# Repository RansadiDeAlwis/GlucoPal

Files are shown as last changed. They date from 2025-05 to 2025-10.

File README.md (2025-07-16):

# GlucoPal 🩺 – Non-Invasive Blood Glucose Monitoring  
**Team NeuroBytes | University of Moratuwa**

---

## 🔍 Project Overview

**GlucoPal** is a **non-invasive, low-cost, portable device** for real-time blood glucose monitoring using **Near-Infrared (NIR) spectroscopy** and **Photoplethysmography (PPG)**. The system addresses the global diabetes epidemic, particularly in regions like **Sri Lanka**, where **20% of adults** are diabetic or pre-diabetic—many undiagnosed due to lack of screening tools.

**Goal:** Eliminate painful and costly finger-prick tests through a user-friendly device powered by optical sensing and AI.

---

## ⚙️ How It Works

1. **Finger Placement**: User places a finger on a 3D-printed sensor clip.
2. **Signal Acquisition**: A 940nm IR emitter/receiver captures PPG signals.
3. **Signal Processing**: ESP32 microcontroller amplifies, filters, and transmits data to a Raspberry Pi.
4. **Model Inference**: A trained **1D ResNet34 model** predicts glucose levels from the PPG data.
5. **Display Output**: Results are shown on an onboard OLED display.

---

## 🧪 Technologies Used

- **Hardware**: ESP32, IR emitter/receiver (940nm), TL084 op-amp, Raspberry Pi, OLED Display
- **Software**: PyTorch, SciPy, NumPy, Matplotlib
- **AI Model**: Customized **1D ResNet34** for regression
- **Signal Features**: Filtering, downsampling, normalization, segmentation
- **Cloud Integration**: **AWS Lambda**, **Amazon S3**, **Amazon DynamoDB**, **MQTT via AWS IoT Core**

---

## ☁️ Cloud Infrastructure (AWS Integration)

GlucoPal is designed with **IoT connectivity and cloud-based data management**, providing secure and scalable storage, processing, and analysis.

### AWS Components

| Service | Role |
|---|---|
| **AWS Lambda** | Serverless preprocessing, validation, and forwarding |
| **Amazon S3** | Stores raw and processed PPG signal data, logs, backups |

---

### Data Flow
ESP32 → AWS → ML Model → ESP32 → Display

---

### Why Cloud?

- **Remote Access**: Patients and clinicians can access historical glucose data remotely.
- **Scalability**: No limits on data storage or concurrent users.
- **Security**: AWS IoT Core ensures secure MQTT communication with TLS.
- **Cost-Effective**: Pay-per-use model via AWS Lambda & S3.
- **Alerts & Automation**: Easy to integrate with AWS SNS or other health record systems.

---

## 🧬 Dataset

- **Source**: University of Science and Technology of Mazandaran, Iran
- **Type**: PPG signals at 2175Hz, labeled with glucose levels

### Preprocessing Pipeline

- Downsampling to **100Hz**
- Bandpass filtering (**0.5–8 Hz**)
- Zero-phase filtering & normalization
- Segmentation into **1-second windows**

---

## 📊 Model Performance

| Metric | Value |
|---|---|
| **Architecture** | Custom **1D ResNet34** |
| **RMSE** | 16.42 mg/dL |
| **MAE** | 13.41 mg/dL |
| **Clarke Error Grid** | Zone A & B (clinically acceptable) |
| **Inference Device** | Raspberry Pi |

---

## 🛠️ Features

- **Non-invasive** measurement
- **On-device display** via OLED
- **Wireless real-time communication** (ESP32 ↔ Raspberry Pi ↔ AWS)
- **Cloud-based storage and alerts**
- **Reusable, sustainable design** (no strips needed)
- **Low-cost components**, locally sourced

---

## Testing Frame

---

## 🔐 Ethics & IP

- **Ethical clearance** in progress for clinical testing.
- **No Personally Identifiable Information (PII)** is stored.
- **Intellectual Property** includes:
  - Custom signal acquisition circuitry
  - 3D-printed ergonomic enclosure
  - Cloud-integrated AI processing pipeline

---

## 🚀 Future Improvements

- **On-device AI inference** (eliminate Raspberry Pi dependency)
- **Edge processing with AWS Greengrass**
- **Clinical fine-tuning** with Sri Lankan patient data
- **Fully portable version** with LTE/Mobile MQTT connectivity

---

## 👨‍🔬 Team NeuroBytes

- **W. M. Ransadi de Alwis**  
- **Pravindu Goonetilleke**  
- **Mohamed Irshad Nadha**  
- **Pulasthi H. J. Udugamasooriya**

### Mentors

- Dr. Navoda Atapattu (Lady Ridgeway Hospital)  
- Dr. Nayana S. Fernando (UoM Faculty of Medicine)

---

## 📘 References

- [PPG Glucose Estimation Research](https://pmc.ncbi.nlm.nih.gov/articles/PMC10331674/)
- [PPG Dataset – Mendeley Data](https://doi.org/10.17632/37pm7jk7jn.3)

---

**Empowering early diabetes detection with innovation and accessibility.**

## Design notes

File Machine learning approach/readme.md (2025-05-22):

# 🤖 GlucoPal: Machine Learning for Non-Invasive Glucose Prediction

This repository contains the machine learning pipeline for **GlucoPal**, a non-invasive glucometer using PPG signals and deep learning. This component is responsible for predicting blood glucose levels from optical signals acquired through an ESP32-based sensor.

---

## 📁 Dataset

- **Source**: [University of Science and Technology of Mazandaran (MUST), Iran](https://doi.org/10.17632/37pm7jk7jn.3)
- **Samples**: 67 raw PPG signals from 23 individuals
- **Sampling Rate**: 2175 Hz
- **Features**:
  - Green LED (550 nm) PPG signals
  - Age, gender
  - Invasively measured blood glucose levels
download (3)

---

## 🛠️ Preprocessing Steps

1. **Downsampling**:
   - From 2175 Hz → 100 Hz using linear interpolation
2. **Filtering**:
   - 3rd-order Butterworth bandpass (0.5–8 Hz) via `scipy.signal`
   - Zero-phase filtering to preserve temporal structure
3. **Normalization**:
   - Standardization to zero mean and unit variance
4. **Segmentation**:
   - Split into 1-second windows (100 samples per segment)

---

## 🧠 Model Architecture – 1D ResNet34

A custom 1D version of ResNet34 was implemented using **PyTorch** for time-series PPG regression.

### 🔧 Structure Overview

- **Input**: (batch_size, 1, 100)
- **Initial Conv1D Layer** (64 filters, kernel size 7) + BatchNorm + ReLU + MaxPooling
- **Residual Blocks**:
  - 3 × [64 filters]
  - Transition: Conv1D → 128
  - 3 × [128 filters]
  - Transition: Conv1D → 256
  - 3 × [256 filters]
- **Global Average Pooling**
- **Dense Layer** (256 units + ReLU)
- **Dropout** (0.5)
- **Output**: 1 neuron (regression output)

---

## 🏋️‍♂️ Training Details

- **Framework**: PyTorch
- **Loss Function**: Mean Squared Error (MSE)
- **Optimizer**: Adam
- **Batch Size**: 64
- **Epochs**: 50 (adjustable)
- **Validation Split**: 20%

---

## 📊 Model Performance

### 📈 Evaluation Metrics
- **Root Mean Squared Error (RMSE)**: `16.42 mg/dL`
- **Mean Absolute Error (MAE)**: `13.41 mg/dL`
- **Clarke Error Grid Analysis**:
  - Majority of predictions in Zones **A** & **B** (clinically acceptable)
  - Minimal predictions in Zones C–E
 
download (1)

## Testing the model 
download (2)

---

## 🖥️ Inference Pipeline

- The trained model runs on a **Raspberry Pi**, receiving PPG data from an ESP32 over Wi-Fi.
- Preprocessing and inference are done on-device using the trained PyTorch model.
- Output is transmitted back to the ESP32 and displayed on an OLED screen.

---

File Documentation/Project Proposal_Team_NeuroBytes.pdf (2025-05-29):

# Non-Invasive Glucometer Using NIR and Photoplethysmography

## Team NeuroBytes

### University of Moratuwa

### GlucoPal

## Team NeuroBytes

Team Leader

W. M. Ransadi de Alwis

200280501137

dealwiswmr.22@uom.lk

0742239385

2nd Year

Team Member 1

Pravindu Goonetilleke

200230802158

goonetillekep.22@uom.lk

0772111411

2nd Year

Team Member 2

Mohamed Irshad Nadha

200253202440

nadhami.22@uom.lk

0771685092

2nd Year

Team Member 3

Pulasthi H. J.
Udugamasooriya

200206100439

udugamasooriyaphj.22@u
om.lk

0716167955

2nd Year

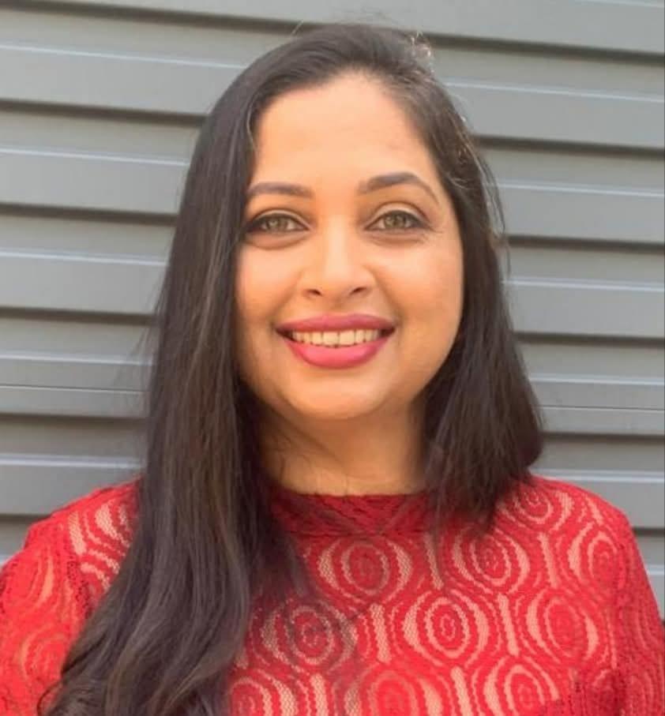
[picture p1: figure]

Team Mentor 1 | Team Mentor 2
Dr. Navoda Atapattu | Dr. Nayana Shiranthini Fernando
738622790V | 715232529V
navodaa@gmail.com | nayanaf@uom.lk
0772995039 | 0777931062
Pediatric Endocrinologist | MBBS,MSc,MD (Community Medicine)
Lady Ridgeway Hospital | Senior Lecturer
| Faculty of Medicine
| University of Moratuwa

## Near-Infrared-Based Glucometer Proposal

## 1. Problem being Addressed and Why it is Important

Diabetes, one of the most common chronic diseases that people have throughout their lives, is expected to surpass all other causes of death in the near future. Diabetes is an autoimmune disease brought on by the body's incapacity to control glucose, or sugar, in the body. While diabetes in itself is harmful, improper treatment of diabetes worsens the situation, by harming and causing other delicate organs in the body to malfunction.

According to the International Diabetes Federation (IDF), 540 million adults, or 10.5% of the global population, had diabetes in 2021. Without effective prevention strategies, this number is projected to rise to 783 million (12.2%) by 2045. In the same year, diabetes was responsible for 6.7 million deaths and incurred healthcare costs amounting to $966 billion, marking a staggering 316% increase over the past 15 years. Additionally, an estimated 541 million individuals worldwide had pre-diabetes in 2021, placing them at a high risk of developing type 2 diabetes. The burden of diabetes disproportionately affects low- and middle-income countries, where three out of four individuals with the condition reside, with many remaining undiagnosed.

Sri Lanka, a country with a population of 22 million, is experiencing a steady rise in diabetes and pre-diabetes cases. Currently, 20% of Sri Lankan adults aged 20 to 79 have either diabetes or pre-diabetes, and one-third of those with diabetes remain undiagnosed. Several factors contribute to this rising trend, including an aging population, increasing obesity rates, urbanization, and reduced physical activity. Between 2011 and 2021, the prevalence of type 2 diabetes surged from 7.6% to 11.3%, reflecting a 68.3% increase. [5] (https://pmc.ncbi.nlm.nih.gov/articles/PMC10462943/)

Early detection and ongoing monitoring are essential to preventing complications and lowering healthcare costs, because of the high prevalence of diabetes and its life-altering effects. However, the lack of easily available and reasonably priced screening techniques means that a lot of people go untreated. By creating a novel, non-invasive diabetes detection and monitoring device, our project seeks to close this gap and offer a practical, affordable, and user-friendly way to enhance early diabetes diagnosis and management.

## 2. Process of Collecting Information about the Problem

We began our research on prevailing issues in the health sector by consulting several medical professionals. Our focus shifted to a specific issue suggested by a pediatric endocrinologist (now acting as our mentor) based on the widespread relevance and influence it has on the healthcare sector; the issue of inconvenience and discomfort presented to diabetic patients, especially children, by the common invasive procedure of measuring blood sugar involving pricking a finger. She emphasized that the issue has been an unaddressed inconvenience in Sri Lanka for a significant time, not only to patients but also to medical professionals like herself.

With an initial idea based on her insights, we expanded our knowledge further by consulting research papers and studies about the issue to better understand the problem. We were able to find a number of studies that recognized this issue [2] [3] [4] [6], and called for the urgent need of an economically feasible and reliable noninvasive procedure/product to measure blood glucose levels. Our research also included an investigation of such possible non-invasive procedures, after which we recognized NIR technology and PPG waveforms as two of the most promising procedures, and decided to develop GlucoPal based on them.

## 3. Brief Description of the Solution

### Overview

Diabetes management relies on accurate blood glucose monitoring, which is traditionally done through invasive blood sampling via pricks. Pricking is often painful, requires expensive test strips, and is not a viable option for continuous glucose monitoring.

This project aims to develop a non-invasive near-infrared (NIR)-based glucometer utilizing an IR emitter and receiver (940nm) to measure blood glucose levels from the finger. The proposed solution will process photoplethysmographic (PPG) signals and peak IR values to train machine learning models for accurate glucose prediction.

### Methodology

1. Hardware Setup
- Use an IR emitter (940nm) and receiver to measure light absorption variations through a fingertip.
- Process the analog signals from the sensor using a microcontroller.
- Convert the analog values into a continuous PPG waveform and extract peak values separately.
2. Signal Processing & Data Collection
- The IR receiver will capture light absorption variations corresponding to blood volume changes.
- The continuous signal will be processed to generate a PPG waveform.
- Peak IR values will be extracted separately for a secondary data analysis approach.
- Data will be collected in correlation with actual blood glucose measurements.
3. Model Training
- PPG Waveform Model: Trained using the PPG waveform and corresponding blood glucose levels.
- Peak IR Value Model: Trained using peak IR values and corresponding blood glucose levels.
- Both models will be evaluated and validated using real-world data to enhance prediction accuracy.

### Rationale

The glucose molecule exhibits its highest absorption peak at 940nm [3], making near-infrared (NIR) sensing at this wavelength suitable for estimating blood glucose levels [7]. However, NIR-based methods alone have demonstrated limited correlation with actual blood glucose levels [3].

To enhance accuracy, we plan to capture Photoplethysmogram (PPG) signals, which measure volumetric blood flow changes using the same sensors. Integration of PPG signals into machine learning algorithms has shown improved predictive capability for blood glucose levels compared to infrared methods alone [3] [6] [8].

By leveraging both techniques, our goal is to significantly improve the accuracy of our device.

### Functional Diagrams

System Architecture

Data Flow

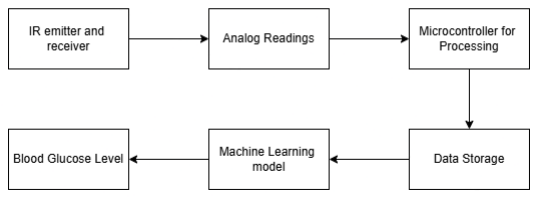
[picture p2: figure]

### Required Resources

Hardware

- 940nm IR emitter and receiver
- Microcontroller (e.g., Arduino, ESP32, or Raspberry Pi)
- Analog-to-Digital Converter (if required)
- Low Noise Amplifier
- Finger clip for sensor placement
- Power supply and necessary wiring

Software

- Python (for data processing and ML model training)
- Machine Learning frameworks (TensorFlow/PyTorch/Scikit-learn)
- Signal processing libraries (SciPy, NumPy, OpenCV for waveform extraction)

Data

- Collection of paired datasets (PPG waveform and blood glucose levels, Peak IR values and blood glucose levels)
- Datasets available online
- Clinical datasets / Volunteer data (if possible)
- Data pre-processing for noise reduction and feature extraction

### Novelty and Uniqueness

- Non-Invasive Glucose Monitoring: Unlike traditional glucometers, this system eliminates the need for finger pricking.
- Dual Model Approach: By using both PPG waveform and peak IR values, the system enhances accuracy and redundancy in glucose prediction.
- Machine Learning Integration: Advanced AI models will improve accuracy over time through adaptive learning.
- Real-Time Monitoring Potential: The system can be extended for continuous glucose monitoring, benefiting diabetic patients with real-time data insights.

### Market Analysis & Competitor Landscape

During our discussions with doctors, a critical pain point became evident: the traditional pricking method for glucose monitoring is far from ideal. It presents several challenges:

- Pain & Discomfort: Patients dislike the frequent finger pricks.
- High Cost: Test strips are expensive, making long-term use burdensome.
- Limited Feasibility for Continuous Monitoring: The method is impractical for real-time glucose tracking.

Recognizing these challenges, we conducted in-depth research and identified a significant market opportunity. While non-invasive glucose monitoring solutions are available globally, they are not widely used in Sri Lanka. Doctors confirmed that the high cost of existing solutions makes them inaccessible to most of Sri Lanka’s population.

This gap provides a unique first-mover advantage for us. By offering an affordable and accessible alternative, we can redefine glucose monitoring in Sri Lanka’s healthcare sector, making it feasible for both hospitals and individual patients.

### Existing Products

Right now, there aren’t many non-invasive glucometers on the market. This is mainly because it’s hard to make accurate predictions. Some devices do exist, but they have major drawbacks. For example, sugarBEAT [1] measures glucose using interstitial fluid (ISF), but ISF sugar levels lag behind the actual blood glucose levels by 4-10 minutes [2].

Other non-invasive glucometers also struggle with accuracy, ease of use, and consistency. Many of them use complex methods that don’t give results as reliable as traditional finger-prick tests.

Another big issue is cost. Most of these devices are very expensive, making them impractical for markets like Sri Lanka. Because of this, there’s still a big need for an affordable and accurate non-invasive glucometer in the country.

## 4. Impact of the Solution on Healthcare

### Impact on the Healthcare Sector

The introduction of a non-invasive glucometer based on Near-Infrared (NIR) sensing and Photoplethysmography (PPG) has the potential to revolutionize diabetes management in Sri Lanka and beyond. The healthcare sector, particularly in developing countries, faces multiple challenges in glucose monitoring, including high costs, limited accessibility, and patient discomfort with invasive methods. GlucoPal directly addresses these issues and provides significant benefits to multiple stakeholders, including patients, healthcare providers, and the government.

### Sustainability of GlucoPal

GlucoPal enhances sustainability by eliminating the dependence on disposable test strips, which contribute significantly to medical waste. Traditional glucose monitoring requires frequent pricking, leading to biohazardous waste and ongoing expenses. Our device, by utilizing Near-Infrared (NIR) technology and Photoplethysmography (PPG), removes the need for invasive procedures, reducing both environmental impact and healthcare costs. Additionally, the device is designed for long-term use with rechargeable batteries and durable components, ensuring minimal replacement needs. This approach not only minimizes medical waste but also provides a reliable, low-maintenance alternative for continuous glucose monitoring, making it a more sustainable choice for diabetes management.

### How GlucoPal Addresses the Problem Statement

Diabetes management relies heavily on frequent blood glucose monitoring, which is traditionally invasive, painful, and costly. GlucoPal directly addresses these challenges by leveraging Near-Infrared (NIR) technology and Photoplethysmography (PPG) to measure blood glucose levels non-invasively. This removes the need for frequent finger pricking, making it more comfortable for users while eliminating the recurring cost of test strips. Additionally, machine learning integration enhances accuracy over time, ensuring reliable glucose level estimation. By providing a practical alternative to conventional methods, our device enables better diabetes management without the drawbacks of invasive testing.

### How Customers Will Benefit from GlucoPal

- Pain-Free Monitoring: Eliminates the need for finger pricks, providing a more comfortable experience for diabetic patients.
- Cost-Effective: Reduces the financial burden by eliminating the need for costly test strips, making glucose monitoring more affordable.

- Increased Accessibility: Offers a practical solution for diabetes patients in Sri Lanka who struggle with the high cost of traditional glucometers.
- Continuous Monitoring: Enables real-time glucose tracking without discomfort, leading to better disease management and early intervention.
- Improved Healthcare Efficiency: Reduces the financial strain on healthcare institutions by offering a non-invasive alternative to traditional glucose testing.
- Better Long-Term Health Outcomes: Encourages frequent monitoring, helping patients manage their condition more effectively and reduce complications.

## 5. References

[1] https://www.medicalexpo.com/prod/nemaura-medical/product-112238-739565.html
[2] https://pmc.ncbi.nlm.nih.gov/articles/PMC7731259/
[3] https://sci-hub.se/downloads/2020-06-05/9a/priyoti2019.pdf
[4] https://pmc.ncbi.nlm.nih.gov/articles/PMC10331674/
[5] https://pmc.ncbi.nlm.nih.gov/articles/PMC10462943/
[6] https://www.mdpi.com/1424-8220/22/12/4452’
[7] https://sci-hub.se/https://doi.org/10.1109/ICAC49085.2019.9103375
[8] https://www.mdpi.com/2076-3417/14/4/1406

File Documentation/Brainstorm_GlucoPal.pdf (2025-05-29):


## University of Moratuwa

## Department of Electronic and Telecommunication Engineering

# Non-Invasive Glucometer Using NIR and Photoplethysmography

## (GlucoPal)

## Project Report

Team NeuroBytes

W. M. Ransadi de Alwis | 200280501137
Pravindu Goonetilleke | 200230802158
Mohamed Irshad Nadha | 200253202440
Pulasthi H. J. Udugamasooriya 200206100439

Mentors:

Dr. Navoda Atapattu – Pediatric Endocrinologist, Lady Ridgeway Hospital Dr. Nayana Shiranthini Fernando – Senior Lecturer, Faculty of Medicine, UoM

May 4, 2025

# Contents

1 Introduction | 3
2 Literature Review | 4
3 Feasibility | 7
4 Functionality | 9
5 Circuitry | 10
6 Enclosure Design | 16
7 Model Training and Results | 18
8 Simulation Results | 23

1

GlucoPal | Team NeuroBytes
9 Regulatory Aspects | 25
10 Data Security and Privacy | 27
11 Impact and Sustainability | 28
12 Limitations and Future Improvements | 29

2

# Chapter 1

# Introduction

## 1.1 Project Overview

Diabetes is a major global health issue and is rapidly becoming one of the leading causes of death. It occurs when the body fails to regulate blood glucose levels, leading to long-term complications that damage vital organs. As of 2021, over 540 million people worldwide were living with diabetes, with numbers projected to reach 783 million by 2045. Alarmingly, most of those affected live in low- and middle-income countries, where diagnosis and treatment are often delayed or inaccessible due to cost. In Sri Lanka, 20% of adults already have diabetes or pre-diabetes, with a third of cases going undiagnosed—largely due to limited screening options and growing lifestyle-related risk factors.

Traditional glucose monitoring methods are invasive and costly, making them impractical for widespread use in resource-limited settings like Sri Lanka. Continuous blood tests can be uncomfortable and unaffordable for many, especially for early detection or frequent monitoring. Our project addresses this gap by developing a non-invasive, low-cost, and user-friendly solution for diabetes detection and monitoring, aiming to improve accessibility, early diagnosis, and long-term health outcomes in communities most at risk.

3

# Chapter 2

# Literature Review

## 2.1 Optical Methods for Non-Invasive Glucose Monitoring

Among the various non-invasive techniques being explored, optical methods have shown promise [1]–[3]. These methods generally rely on the quantification of glucose molecules, which exhibit distinct characteristics when interacting with light at different frequencies, such as visible light, near-infrared (NIR), and ultrasonic waves [1]. While optical methods enable real-time quantitative monitoring, they have faced challenges in matching the accuracy of traditional electrochemical blood glucose meters in clinical settings [1].

### 2.1.1 Near-Infrared (NIR) Spectroscopy

Near-infrared spectroscopy is a promising non-invasive blood glucose monitoring technology [1], [2]. The principle involves analyzing a beam of infrared light that passes through or is reflected by human tissue to determine glucose content [1]. Glucose molecules interact with NIR light, causing absorption and scattering [1]. NIR light is particularly effective as it can penetrate body fluids and soft tissues [1]. The concentration of blood sugar can be estimated by detecting and calibrating the NIR spectrum absorption value after the light has partially absorbed while passing through human tissue [1].

Glucose molecules exhibit distinct absorption patterns in the 700–1100 nm wavelength region, which is also where most biological cells and tissues are relatively transparent [2]. Wavelengths around 780 nm and 940 nm are noted for their reaction in response to glucose concentration [2]. Specifically, 940 nm is considered a reliable wavelength for glucose detection because it has a relatively high absorption value for glucose in blood compared to other blood components and exhibits less interference from water absorption than wavelengths above 1000 nm [2]. The relationship between substance concentration and light absorption/transmittance is described by Beer-Lambert’s law, where the decrease in light intensity is proportional to the concentration and path length [2]. By detecting the amount of transmitted light, the concentration can be calculated [2].

## 2.2 Photoplethysmography (PPG)

Photoplethysmography (PPG) is a non-invasive optical technique used to detect blood volume changes in the peripheral circulatory system [3], [4]. PPG signals can be obtained

4

from various body sites, such as the wrist, fingertip, or earlobe [3], [4]. The signal is generated by shining light (e.g., from LEDs at different wavelengths) into the tissue and measuring the light that is transmitted or reflected using a photodetector [4]. The amount of light absorbed or scattered varies with the pulsatile blood flow and the composition of the tissue and blood, including glucose levels [1], [2]. Glucose affects light scattering; a rise in glucose levels leads to decreased scattering and reduced total absorbed light [1].

Recent advancements in PPG technology, coupled with machine learning, have shown promise for non-invasive and economical blood glucose monitoring [4]. Studies have focused on using PPG signals from various sites, including the wrist, to estimate blood glucose levels [4].

## 2.3 Studies Combining NIR and PPG

Several research efforts have explored combining NIR principles with PPG for non-invasive glucose estimation. One study proposed a non-invasive blood glucose measurement system using Near Infra-Red Spectroscopy at a 940 nm wavelength [2]. This system utilizes a 940 nm IR emitter and a photodiode receiver, typically placed on a fingertip, to measure the amount of NIR radiation passing through the blood vessels [2]. The voltage output of the photodiode, which depends on the transmitted light, is correlated with blood glucose concentration [2].

A key challenge in such optical measurements is the influence of tissue thickness or width, as absorbance is directly proportional to the path length of light [2]. To compensate for variations in finger depth, one proposed method involves using an additional IR sensor to optically measure the distance between the emitter and receiver and normalize the IR absorbance readings to eliminate the effect of finger width [2].

Another approach combines dual-wavelength PPG (using 660 nm red light and 900 nm infrared light) with bioelectrical impedance measurements to estimate blood glucose [3]. The study noted that glucose has different absorption rates for different wavelengths [3].

## 2.4 Feature Extraction and Data Analysis

Extracting meaningful features from the acquired optical signals is crucial for accurate glucose estimation. For PPG signals, this can involve analyzing the waveform’s characteristics. Statistical features such as the mean, variance, skewness, kurtosis, standard deviation, and information entropy derived from PPG signal peaks have been used [3].

Once features are extracted, machine learning algorithms are applied to build predictive models for blood glucose levels [3], [4]. Techniques explored include polynomial regression [2], Back-Propagation Neural Networks (BPNN) [3], and various gradient boosting algorithms such as CatBoost, XGBoost, LightGBM, and random forest [4]. Studies have shown that these machine learning algorithms can achieve high levels of accuracy in predicting blood glucose from PPG and other physiological signals, with performance evaluated using metrics like Pearson’s r, Mean Squared Error (MSE), Mean Absolute Error (MAE), R2 score, and Clarke Error Grid Analysis (EGA) [3], [4]. Combining different types of features, such

5

as PPG waveform-based features and EMD-based features, can improve overall prediction accuracy [4]. The combination of dual-wavelength PPG and bioelectrical impedance features using a BPNN achieved an R2 of 0.997 and 100% of results in the clinically accurate region A of the Clarke EGA in one study [3].

## 2.5 Challenges

Despite significant progress, several technical bottlenecks hinder the widespread application and accuracy of non-invasive blood glucose monitoring technologies, including those based on optical methods like NIR spectroscopy and PPG [1], [3], [4]. Key challenges include:

- Weak signal detection: The signal related to glucose can be weak and requires effective amplification methods [1].
- Individual variations: Measurement accuracy is impacted by individual differences in human physiology and dynamic changes in body components [1].
- Measurement site: Identifying effective and consistent measurement sites (such as fingers or tongue tips) and developing supporting facilities for dynamic monitoring is necessary [1].
- Spectral overlap: Overlapping spectra from various tissue components make it challenging to accurately extract glucose-specific information, requiring effective extraction methods [1].
- Signal Noise and Artifacts: Motion artifacts and other noise can affect signal quality and accuracy, requiring signal processing techniques like filtering [3].
- Accuracy vs. Invasive Methods: The accuracy of current non-invasive technologies is still often not comparable to mainstream invasive methods in clinical practice [1].

6

# Chapter 3

# Feasibility

## 3.1 Hardware Components

Component | Available At (Store + Link) | Price (LKR)
940nm IR Emitter | Tronic LK (https://tronic.lk/product/ir-led-5mm-infrared-emitter-940nm) | 10
940nm IR Receiver | Tronic LK (https://tronic.lk/product/ir-led-5mm-infrared-receiver-940nm) | 20
ESP32 Microcontroller | Tronic LK (https://tronic.lk/product/nodemcu-esp32s-wifi-bluetooth-dual-mode-iot-dev-board) | 1340
Raspberry Pi | Tronic LK (https://tronic.lk/product/raspberry-pi-4-model-b-2gb-original-uk) | 23600**
TL084CN Operational Amplifier | Tronic LK (https://tronic.lk/product/tl084cn-amplifier) | 50
3D Printed Finger Clip | Rysera (https://3dprinting.rysera.com/) | 4000*
Li-Po Battery (1200mAh, 3.7V) | Tronic LK (https://tronic.lk/product/3-7v-1200mah-lipo-battery) | 900
Boost Converter (XL6009) | Tronic LK (https://tronic.lk/product/xl6009-3-32v-to-5-35v-4a-dc-to-dc-adjustable-step-up-bo) | 300
Charging Module (TP4056) | Tronic LK (https://tronic.lk/product/tp4056-5v-1a-micro-usb-18650-special-lithium-battery-ch) | 60
OLED Display (SSD1306 128x64) | Tronic LK (https://tronic.lk/product/0-96-inch-128x64-oled-display-module-blue-i2c-iic) | 540
Custom PCB (if needed) | JLCPCB (International Shipping) (https://jlcpcb.com) | 6000*
Total Cost | | 36,820

Table 3.1: Component List with Source and Estimated Price

*Prices for the PCB and 3D printing are approximate, and can be brought down when producing in bulk. Further, the PCB cost is for 5 PCBs (minimum order from JLCPCB.)

**Since the raspberry pi serves as a central server, it isn’t included in the price of GlucoPal.

## 3.2 Software and AI Technologies

- The deep learning model is developed using Pytorch.
- It will run on Raspberry Pi, a capable edge-computing device.
- The ESP32 captures PPG signals and transmits them to the Raspberry Pi via Wi-Fi.

7

- The Raspberry Pi runs inference using the trained model and sends the glucose value back to the ESP32.
- The OLED Display (SSD1306) shows the result to the user.

All hardware components are either available locally in Sri Lanka or can be fabricated using local services. Additionally, if needed, the custom PCB for the sensor circuit can be ordered from international PCB manufacturing services such as JLCPCB, (https://jlcpcb.com) which offers affordable pricing and fast shipping to Sri Lanka.

The selected technologies are feasible and practical for implementing a non-invasive glucometer using current embedded hardware and machine learning platforms.

8

# Chapter 4

# Functionality

The following outlines the end-to-end functionality of the non-invasive glucometer system:

1. Finger Placement: The user places their finger between a custom 3D-printed clip that houses the IR emitter and receiver.
2. PPG Signal Acquisition: A 940nm infrared emitter and receiver detect variations in light absorption caused by blood flow, producing a photoplethysmography (PPG) waveform.
3. Signal Conditioning: The weak analog PPG signal is amplified and filtered using a TL084CN operational amplifier configured as an instrumentation amplifier. This enhances signal clarity by reducing noise.
4. Microcontroller Sampling: The conditioned analog signal is read by the ESP32 microcontroller through its analog-to-digital converter (ADC). The ESP32 then sends this data wirelessly to a Raspberry Pi over Wi-Fi.
5. Signal Processing and Inference: The Raspberry Pi preprocesses the received signal by filtering and segmenting it. Each segment is passed through a trained machine learning model developed using TensorFlow. The model estimates the blood glucose level for each segment, removes outliers, and computes an average value.
6. Display Output: The final glucose level is sent back to the ESP32, which displays it on an OLED screen (SSD1306, 128x64 resolution).

9

# Chapter 5

# Circuitry

## Power Supply and Distribution

- A rechargeable 1200mAh Li-Po battery (2.7V nominal) serves as the primary power source.
- The battery is connected to both:

– A TP4056 charging module, which enables safe USB-based charging.

– An XL6009 boost converter, which steps up the voltage to 5V to power the main circuit.

- The 5V output from the boost converter is supplied to the PCB, which powers both the ESP32 microcontroller and the instrumentation amplifier circuit.

10

## Main PCB Layout

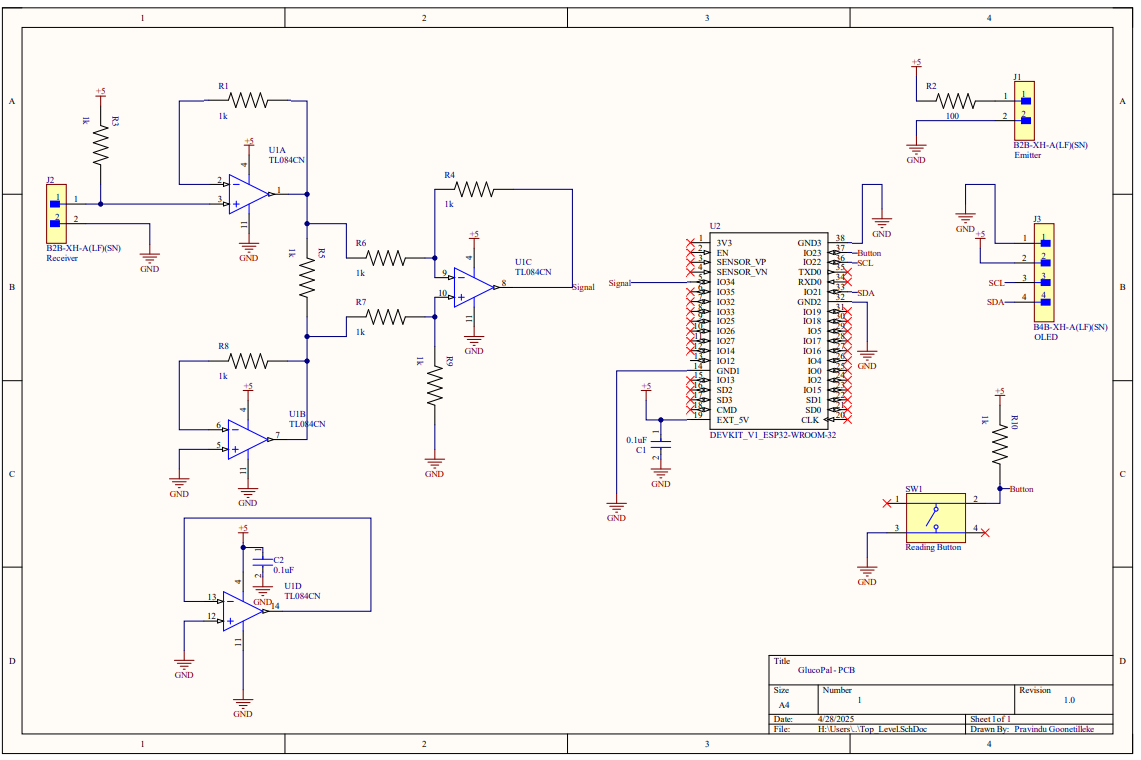
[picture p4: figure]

Figure 5.1: PCB schematic

- Sensor Inputs: JST connectors interface with the IR emitter and photodiode mounted in the finger clip.
- Instrumentation Amplifier: The PPG signal from the IR receiver is fed into a TL084CN-based instrumentation amplifier for amplification and noise suppression. The amplified signal is routed to the ADC pin of the ESP32.

11

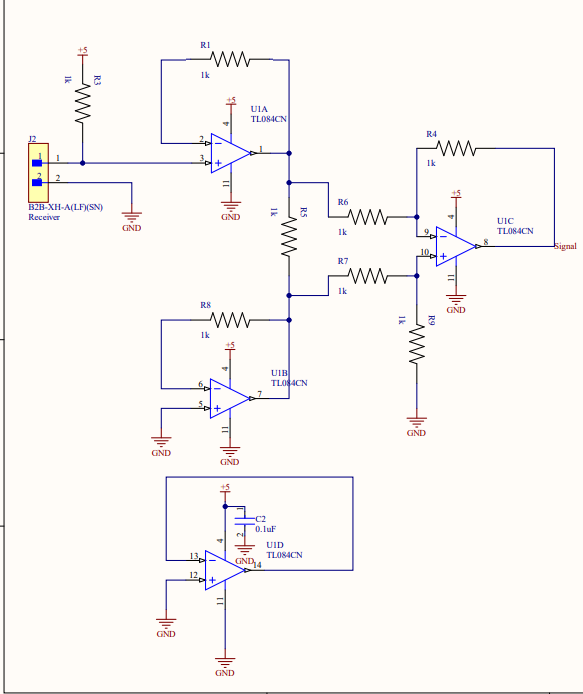
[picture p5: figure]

Figure 5.2: Instrumentation Amplifier

- Microcontroller: An ESP32 microcontroller handles signal acquisition, Wi-Fi communication, and OLED interfacing.

12

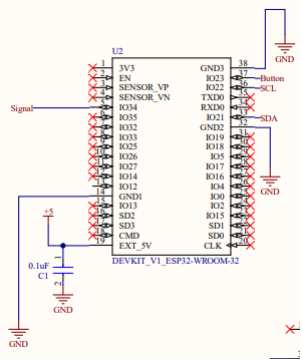
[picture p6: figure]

Figure 5.3: MCU : ESP32 Devkit V1

- User Interface: A tactile pushbutton is connected to the ESP32. When pressed, it initiates a new measurement cycle.
- Display Interface: A JST connector links the ESP32 to the OLED display (SSD1306, 128x64), which shows the final glucose reading.

13

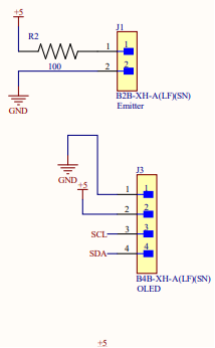
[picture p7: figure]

Figure 5.4: Peripherals

## PCB Fabrication

The entire circuit is designed for single-board integration. The PCB can be fabricated through services like JLCPCB or similar vendors, allowing for high-quality production and

14

easy assembly.

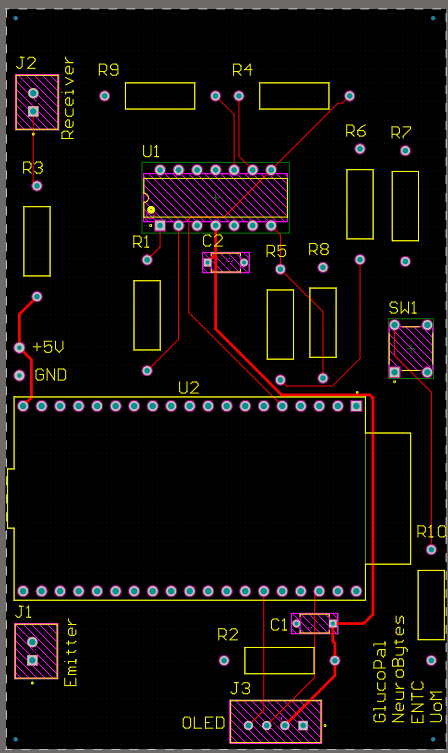
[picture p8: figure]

Figure 5.5: PCB Top Layer

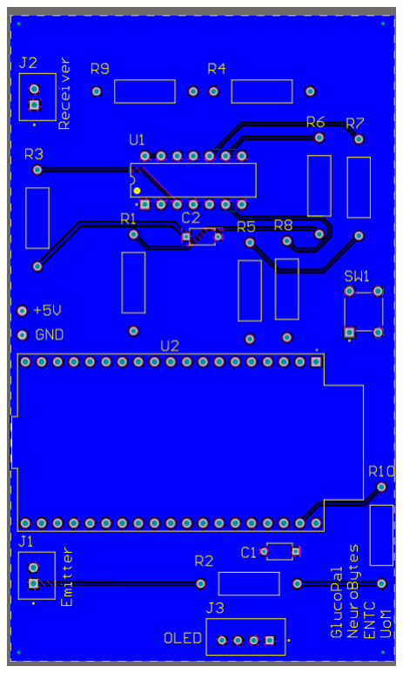
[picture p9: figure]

Figure 5.6: PCB Bottom
Layer

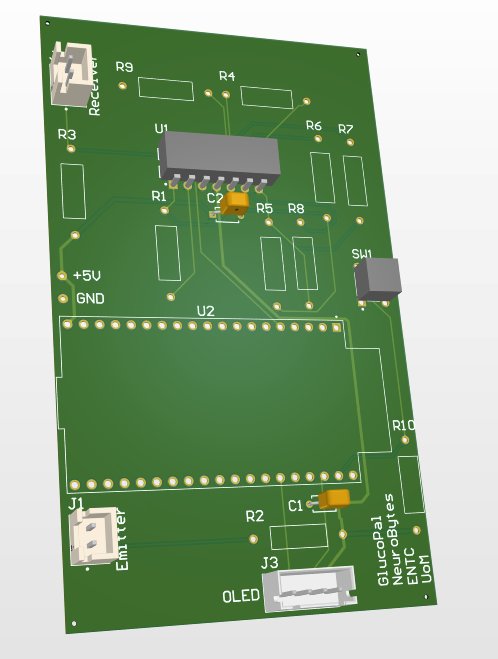
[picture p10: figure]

Figure 5.7: PCB 3D View

15

# Chapter 6

# Enclosure Design

The device enclosure has been custom-designed to house and support all essential components while ensuring user comfort and measurement accuracy. It consists of two interlocking parts:

- Bottom Housing: This section includes a groove where the user places their finger during measurement. It is also designed to securely mount the main PCB, power circuitry, OLED display, and buttons.
- Top Cover: This part fits snugly over the bottom housing and contains a second groove aligned with the transmitter-receiver sensor pair. It ensures proper alignment and shielding of the PPG receiver for optimal signal acquisition.

The enclosure also includes:

- A dedicated power button and a separate reading trigger button on the top surface for user interaction.
- An accessible charging port to charge the internal battery.

The design prioritizes usability, compactness, and integration, making the device portable and user-friendly for non-invasive blood glucose monitoring.

16

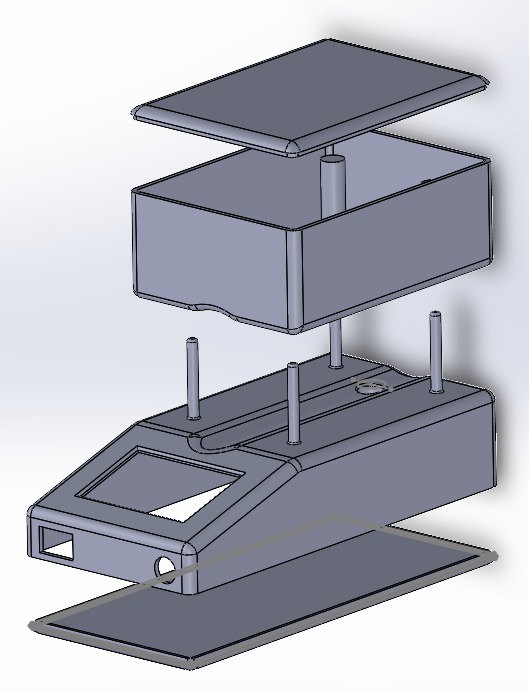
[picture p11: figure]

Figure 6.1: Enclosure

17

# Chapter 7

# Model Training and Results

We went through several research papers involving using PPG signals to predict the blood glucose levels.[5]. For the model building process we refereed the [5].

## 7.1 Dataset Description

The dataset used to train the deep learning model was collected by the Digital Systems Research Team at the University of Science and Technology of Mazandaran (MUST), Iran.
[6] It contains 67 raw photoplethysmography (PPG) signals, sampled at a high frequency of 2175 Hz, from 23 individuals. Each sample is labeled with the participant’s age, gender, and invasively measured blood glucose level, making it suitable for the purpose of our project. The PPG signals were obtained using a green LED pulse sensor (550 nm) and a photodiode receiver, processed through amplification and filtering circuits, and digitized using an Atmega328 microcontroller. Blood glucose levels were measured using a standard Accu-Chek Active device. The dataset includes raw signals, corresponding labels, and signal plots. It is an open-source dataset, publicly available for research and development purposes.

## 7.2 Data Preprocessing

### 7.2.1 Downsampling

To reduce computational load and processing time, the original PPG signal, sampled at 2175 Hz, was downsampled to 100 Hz. This was done to balance between retaining essential information and reducing the dimensionality of the data. The process involved resampling the signal by interpolating between the original samples to generate a lower frequency signal, using linear interpolation. This step helps improve efficiency without significantly losing relevant signal features.

### 7.2.2 Signal Filtering and Normalization

- Butterworth Filter Design: Using the scipy.signal library, a third-order bandpass Butterworth filter was designed with cutoff frequencies of 0.5 Hz and 8 Hz. This configuration helps retain the physiological frequency components of the PPG signal while effectively removing low-frequency drift and high-frequency noise.

18

- Zero-phase Filtering: The filtered signal was processed using zero-phase filtering, also implemented via scipy.signal, to eliminate phase distortion. This approach applies the filter forward and backward, preserving the temporal structure of the signal and ensuring signal integrity.
- Normalization: The filtered signal was then normalized by subtracting the mean and dividing by the standard deviation. This standardization process ensures the signal has zero mean and unit variance, facilitating more efficient and stable model training.

## 7.3 Segmentation

To standardize the input length and improve computational efficiency, the PPG signal was divided into smaller, fixed-length segments. This was achieved by splitting the signal into consecutive windows of 1 second each, based on the sampling frequency (100 Hz). As a result, each segment contained 100 samples, enabling consistent input size for model training and better feature extraction from shorter, informative intervals.

## 7.4 Model Architecture: Customized ResNet34 Model

In the research paper we studied[5], three advanced deep learning models ResNet34, VGG16, and a CNN-LSTM with Attention—were explored for PPG signal analysis. Among these, ResNet34 demonstrated the best performance in terms of prediction accuracy and generalization ability. Therefore, we chose to implement a customized 1D ResNet architecture for training the model.

### 7.4.1 Framework and Libraries

The model was developed using PyTorch, a widely-used deep learning framework, along with modules from:

- torch.nn – for defining neural network layers
- torch.nn.functional – for activation functions and element-wise operations

### 7.4.2 Input and Data Flow

- Input Shape: The model accepts 1D PPG signal data with a shape of (batch size, 1, 100) where 100 corresponds to the number of time steps (or samples per PPG segment) at
a 100 Hz sampling rate.
- Each segment is passed through the architecture for blood glucose level (BGL) prediction.

### 7.4.3 Model Structure

The architecture consists of the following layers:

- Initial Conv1D Layer:

– 64 filters, kernel size 7, padding 3

19

– Followed by BatchNorm1d and ReLU activation

– MaxPooling1d layer with kernel size 3 for downsampling

- Residual Blocks:

– Layer1: Three ResidualBlocks with 64 filters.

– Transition Layer 1: A Conv1D layer with 128 filters, BatchNorm1d, and ReLU activation.

– Layer2: Three ResidualBlocks with 128 filters.

– Transition Layer 2: A Conv1D layer with 256 filters, BatchNorm1d, and ReLU activation.

– Layer3: Three ResidualBlocks with 256 filters.

- Each ResidualBlock consists of:

– Two Conv1D layers (kernel size 3, padding 1), followed by BatchNorm1d and ReLU
– A skip connection for residual learning
- Pooling and Dense Layers:

– MaxPooling1d layer (kernel size 2) after each residual layer group for progressive downsampling.

– Global Average Pooling: A global average pooling layer that reduces the dimensionality of the output to a 1D vector.

– Fully Connected Layer: A dense layer with 256 units and ReLU activation.

– Dropout Layer: A Dropout layer with a dropout rate of 0.5 for regularization.

– Output Layer: The final dense layer has 1 unit with linear activation for regression output (predicting the blood glucose level).

### 7.4.4 Output

- A single continuous value representing the predicted blood glucose level (BGL) for the input PPG segment.

## 7.5 Model Evaluation and Accuracy

To assess the performance of our blood glucose prediction model, we conducted a comprehensive evaluation using both quantitative and clinical metrics. These evaluations aim to determine not only how well the model performs statistically but also how clinically acceptable its predictions are.

### 7.5.1 Quantitative Metrics for Predictive Accuracy

We employed two widely accepted metrics for evaluating predictive models:

20

- Root Mean Squared Error (RMSE): RMSE provides a measure of the average magnitude of error between predicted and actual blood glucose values, expressed in mg/dL. It penalizes larger errors more heavily due to squaring of residuals:

RMSE =

### vuut

1
n

Xn

i=1

(Yi − Yˆ
i)

2

For our model:
Test RMSE = 16.42 mg/dL
- Mean Absolute Error (MAE): MAE quantifies the average absolute differences between predicted and actual values, treating all errors equally:

MAE = 1
n

Xn

i=1

|Yi − Yˆ
i

For our model:
Test MAE = 13.41 mg/dL

These values indicate that the model achieves a relatively low prediction error, demonstrating good accuracy for practical applications.

### 7.5.2 Clinical Accuracy using Clarke Error Grid (CEG) Analysis

Beyond statistical evaluation, we conducted a Clarke Error Grid (CEG) analysis to assess the clinical significance of the model’s predictions. The CEG classifies predictions into five zones:

- Zone A: Clinically accurate predictions.
- Zone B: Benign errors with no impact on clinical outcome.
- Zone C: Overcorrected errors leading to unnecessary treatment.
- Zone D: Potentially dangerous errors from missed hypo/hyperglycemia.
- Zone E: Critical errors with opposite treatment suggestions.

The Clarke Error Grid plot (see Figure 7.1) illustrates the distribution of predicted vs. reference glucose values across these zones. Most of the predictions fall within Zone A and Zone B, indicating high clinical acceptability. Only a few points lie in Zones C–E, suggesting minimal risk of clinically significant errors.

21

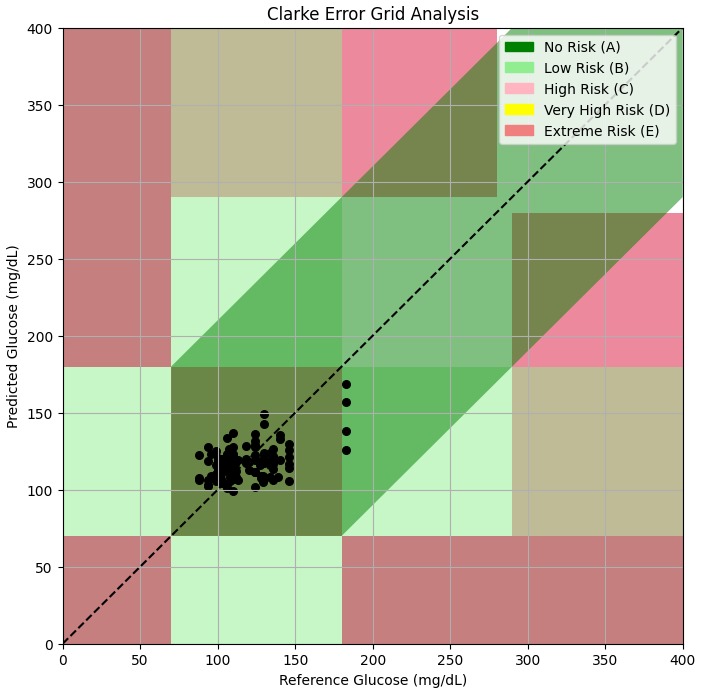
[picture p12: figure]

Figure 7.1: Clarke Error Grid showing the clinical accuracy of the model’s glucose predictions

22

# Chapter 8

# Simulation Results

## 8.1 Simulation and Preliminary Inference

To simulate real-world operation and test the initial performance of our system, we collected sample PPG signals using an early prototype of our non-invasive device.

By observing the following signals, we can see how the pre-processing succeeds in removing most of the noise as well as variations due to finger motion.

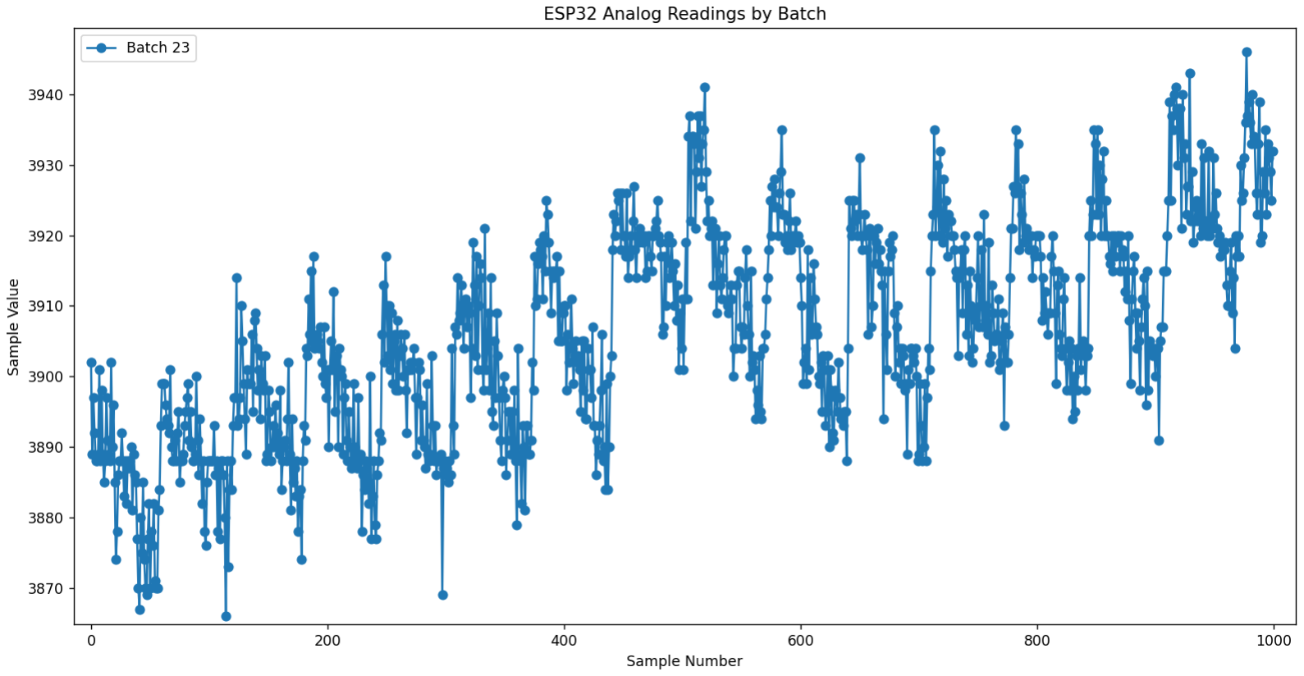
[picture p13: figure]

Figure 8.1: Raw PPG Output from ESP32

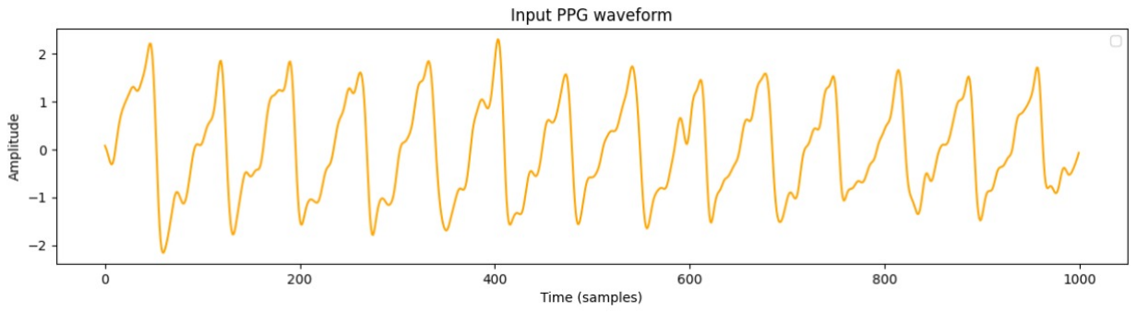
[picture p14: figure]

Figure 8.2: PPG After Pre-Processing

23

These signals were then input into the current deep learning model to perform inference and estimate the blood glucose level.

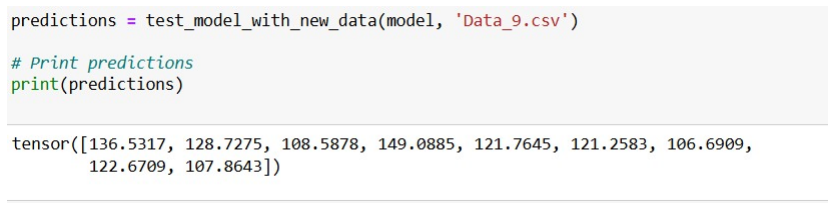
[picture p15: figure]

Figure 8.3: Model Inference Result on Prototype Data

As shown in Figure 8.3, the model predicted a glucose value that significantly deviated from the actual ground truth measurement of 90 mg/dL, obtained using a standard invasive glucometer.

This error is attributed to the fact that the current model has not yet been fine-tuned using our own device’s PPG data. The model was trained on publicly available datasets, which may not fully reflect the characteristics of our hardware and signal acquisition setup.

To address this, we are currently in the process of obtaining ethical approval from the Faculty of Medicine, University of Moratuwa to collect paired PPG and glucometer readings from volunteers. This dataset will be used to fine-tune and validate the model for improved accuracy in real-world use.

24

# Chapter 9

# Regulatory Aspects

## 9.1 Data Collection and Ethical Approval

To fine-tune our deep learning model for better accuracy, we are in the process of collecting a custom dataset. This dataset will include:

- Ground Truth: Blood glucose level readings measured using an FDA-approved invasive glucometer.
- Input Signal: Corresponding PPG waveforms captured using our non-invasive prototype device.

No personal or identifiable data will be collected, stored, or shared. Only the PPG waveform and matched glucose readings will be used strictly for the purpose of model training and evaluation.

To ensure that our data collection process adheres to ethical standards, we are currently seeking approval from the Faculty of Medicine, University of Moratuwa. This ethical review will ensure that all necessary medical and human subject research protocols are followed appropriately.

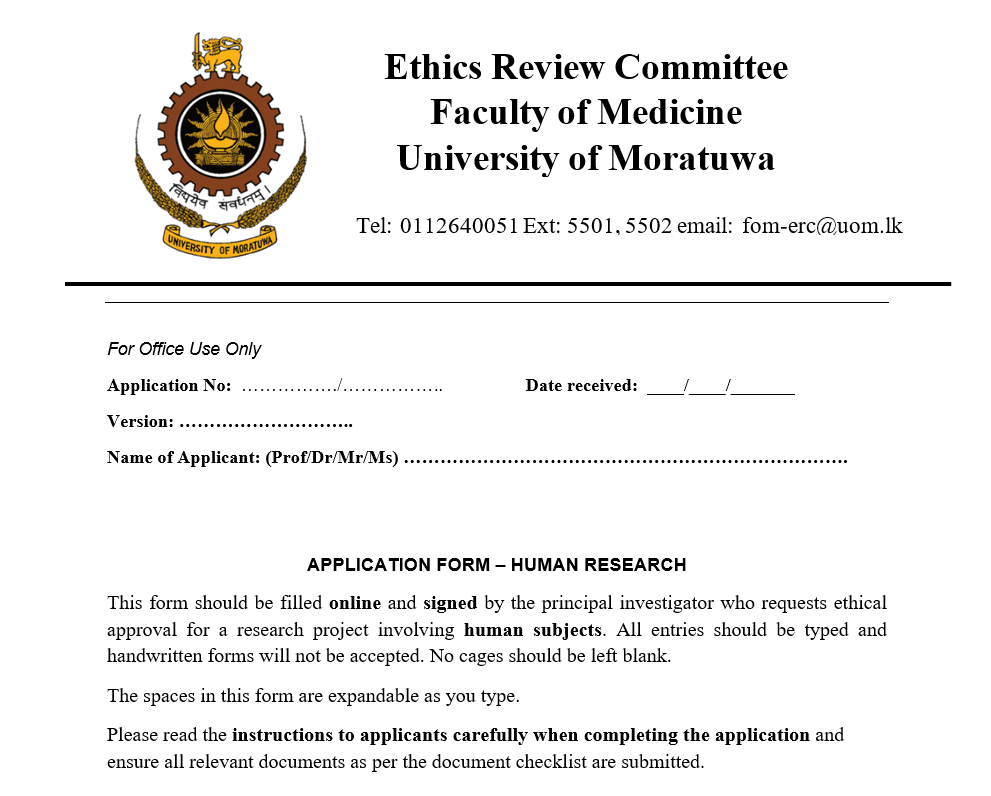
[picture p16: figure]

Figure 9.1: Ethics Review Committee Application

25

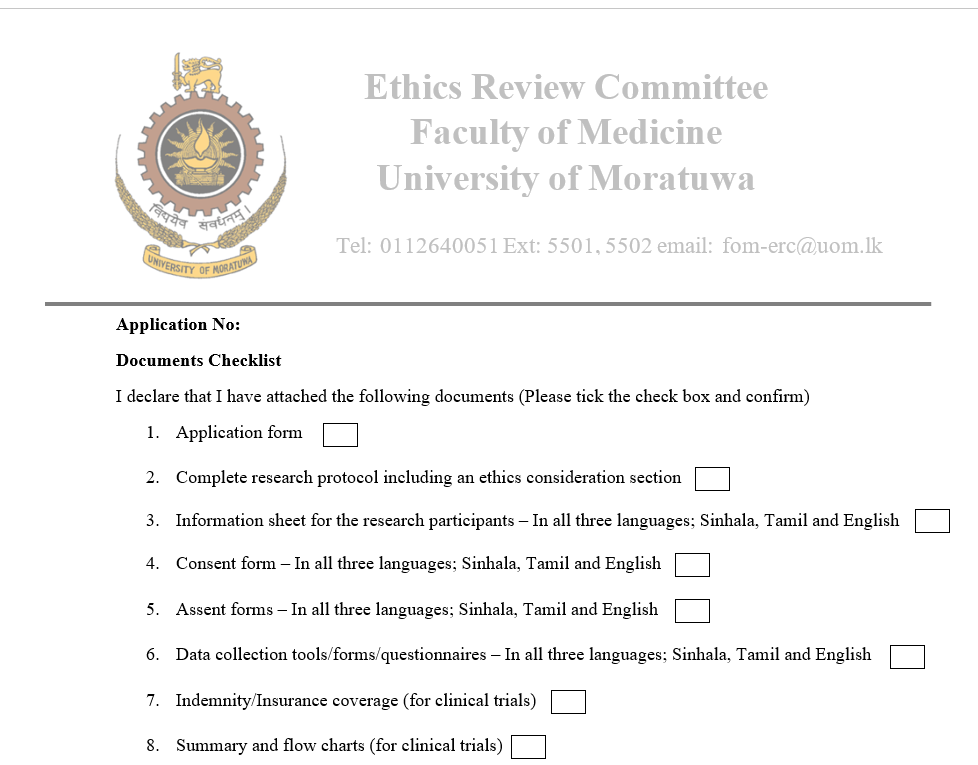
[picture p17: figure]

Figure 9.2: ERC Checklist

All procedures will be conducted with full ethical considerations, and participation will be voluntary. Data will be anonymized and handled in compliance with institutional and research ethics guidelines.
The data to be collected includes:
- Blood glucose readings using a standard invasive glucometer (for ground truth).
- Corresponding PPG waveforms captured using our non-invasive device.

## 9.2 Intellectual Property (IP) Considerations

- The machine learning architecture used in our project is based on ResNet, a publicly available deep learning model. We do not claim ownership of the architecture itself.
- Our implementation leverages open-source libraries such as TensorFlow and PyTorch, which are used under their respective permissive licenses.
- Public datasets were used during the development phase to train and validate our model. These datasets are cited appropriately, and we do not claim IP over them.
- The trained model weights generated through our pipeline may be considered part of our IP, as they reflect specific optimizations and fine-tuning performed by our team.
- The signal processing pipeline and integration with our custom-built non-invasive PPG acquisition device represent potential IP contributions, particularly in hardware design and system integration.

We acknowledge the foundational work in the field and have cited all external sources used. Any novel contributions, particularly in device design and model integration, will be documented for potential IP protection or publication.

26

# Chapter 10

# Data Security and Privacy

Our project utilizes machine learning models trained on publicly available datasets as well as limited, anonymized data collected with the approval of the Faculty of Medicine, University of Moratuwa. The data used for fine-tuning includes photoplethysmogram (PPG) signals from our non-invasive device and corresponding blood glucose readings from a standard invasive glucometer. No personally identifiable information (PII) is collected, stored, or processed at any stage.

To ensure data security and compliance with ethical standards:

- All collected data is anonymized at the source, containing only signal values and reference glucose levels.
- No storage of user profiles, medical history, or biometric identifiers is performed.
- Data is stored temporarily in local, access-controlled systems only for the purpose of model evaluation and fine-tuning.

27

# Chapter 11

# Impact and Sustainability

## 11.1 Impact on the Healthcare Sector

The introduction of a non-invasive glucometer based on Near-Infrared (NIR) sensing and Photoplethysmography (PPG) has the potential to revolutionize diabetes management in Sri Lanka and beyond. The healthcare sector, particularly in developing countries, faces multiple challenges in glucose monitoring, including high costs, limited accessibility, and patient discomfort with invasive methods. GlucoPal directly addresses these issues and provides significant benefits to multiple stakeholders, including patients, healthcare providers, and the government.

## 11.2 Sustainability of GlucoPal

GlucoPal enhances sustainability by eliminating the dependence on disposable test strips, which contribute significantly to medical waste. Traditional glucose monitoring requires frequent pricking, leading to biohazardous waste and ongoing expenses. Our device, by utilizing Near-Infrared (NIR) technology and Photoplethysmography (PPG), removes the need for invasive procedures, reducing both environmental impact and healthcare costs. Additionally, the device is designed for long-term use with rechargeable batteries and durable components, ensuring minimal replacement needs. This approach not only minimizes medical waste but also provides a reliable, low-maintenance alternative for continuous glucose monitoring, making it a more sustainable choice for diabetes management.

28

# Chapter 12

# Limitations and Future Improvements

## 12.1 Limitations:

At present, the system relies on a Raspberry Pi as the main processing unit. The ESP32 microcontroller is only used for data acquisition, while model training and inference are performed on the Raspberry Pi. This design imposes several constraints:

- Increased hardware cost and overall system complexity.
- Reduced portability due to requirement of Wi-Fi connection.
- Data must be transmitted between the ESP32 and Raspberry Pi, introducing latency and raising potential data security concerns.

Further, the current machine learning model has been developed and tested on publicly available datasets, but it does not yet perform reliably when applied to data collected using our own hardware.

## 12.2 Future Improvements:

To address these limitations, the following enhancements are planned:

- Model Optimization: We aim to optimize and compress the deep learning model so that it can be deployed directly on the ESP32. This would allow the device to function as a standalone system, removing the need for a Raspberry Pi or cloud-based processing.
- Data-Specific Fine-Tuning: We plan to fine-tune the model using PPG and blood glucose data collected through our own hardware setup. This will improve the model’s accuracy and reliability when applied to real-world use.
- Improved Portability and Security: Running the model on-device will result in lower power consumption, reduced production cost, and better protection of sensitive health data since no transmission to external servers will be necessary.

29

# Bibliography

[1] J. Wu, Y. Liu, H. Yin, and M. Guo, “A new generation of sensors for non-invasive blood glucose monitoring,” Am J Transl Res, vol. 15, 6 2023.
[2] A. T. Priyoti, S. J. Jim, S. Hossain, S. Mahmud, S. Salvin, and A. Bhattacharjee, “Non-invasive blood glucose measurement using near infra-red spectroscopy,” in Proc. IEEE International Conference on Innovations in Electrical, Electronics, Instrumentation and Media Technology (ICEEIMT), 2019.
[3] C.-T. Yen, U.-H. Chen, G.-C. Wang, and Z.-X. Chen, “Non-invasive blood glucose estimation system based on a neural network with dual-wavelength photoplethysmography and bioelectrical impedance measuring,” Sensors, vol. 22, no. 12, 2022.
[4] S. Satter, M. S. Turja, T.-H. Kwon, and K.-D. Kim, “EMD-based noninvasive blood glucose estimation from PPG signals using machine learning algorithms,” Appl. Sci., vol. 14, no. 4, 2024.
[5] J. Doe and A. Smith, “Non-invasive blood glucose monitoring using ppg signals with deep learning,” Nature Scientific Reports, vol. 14, no. 1, 2024. [Online]. Available: https://pmc.ncbi.nlm.nih.gov/articles/PMC10331674/.
[6] A. Kermani and H. Esmaeili, The dataset of photoplethysmography signals collected from a pulse sensor to measure blood glucose level, https : / / doi . org / 10 . 17632 / 37pm7jk7jn.3, (https://doi.org/10.17632/37pm7jk7jn.3) Mendeley Data, Version 3, University of Science and Technology of Mazandaran, 2023.

30

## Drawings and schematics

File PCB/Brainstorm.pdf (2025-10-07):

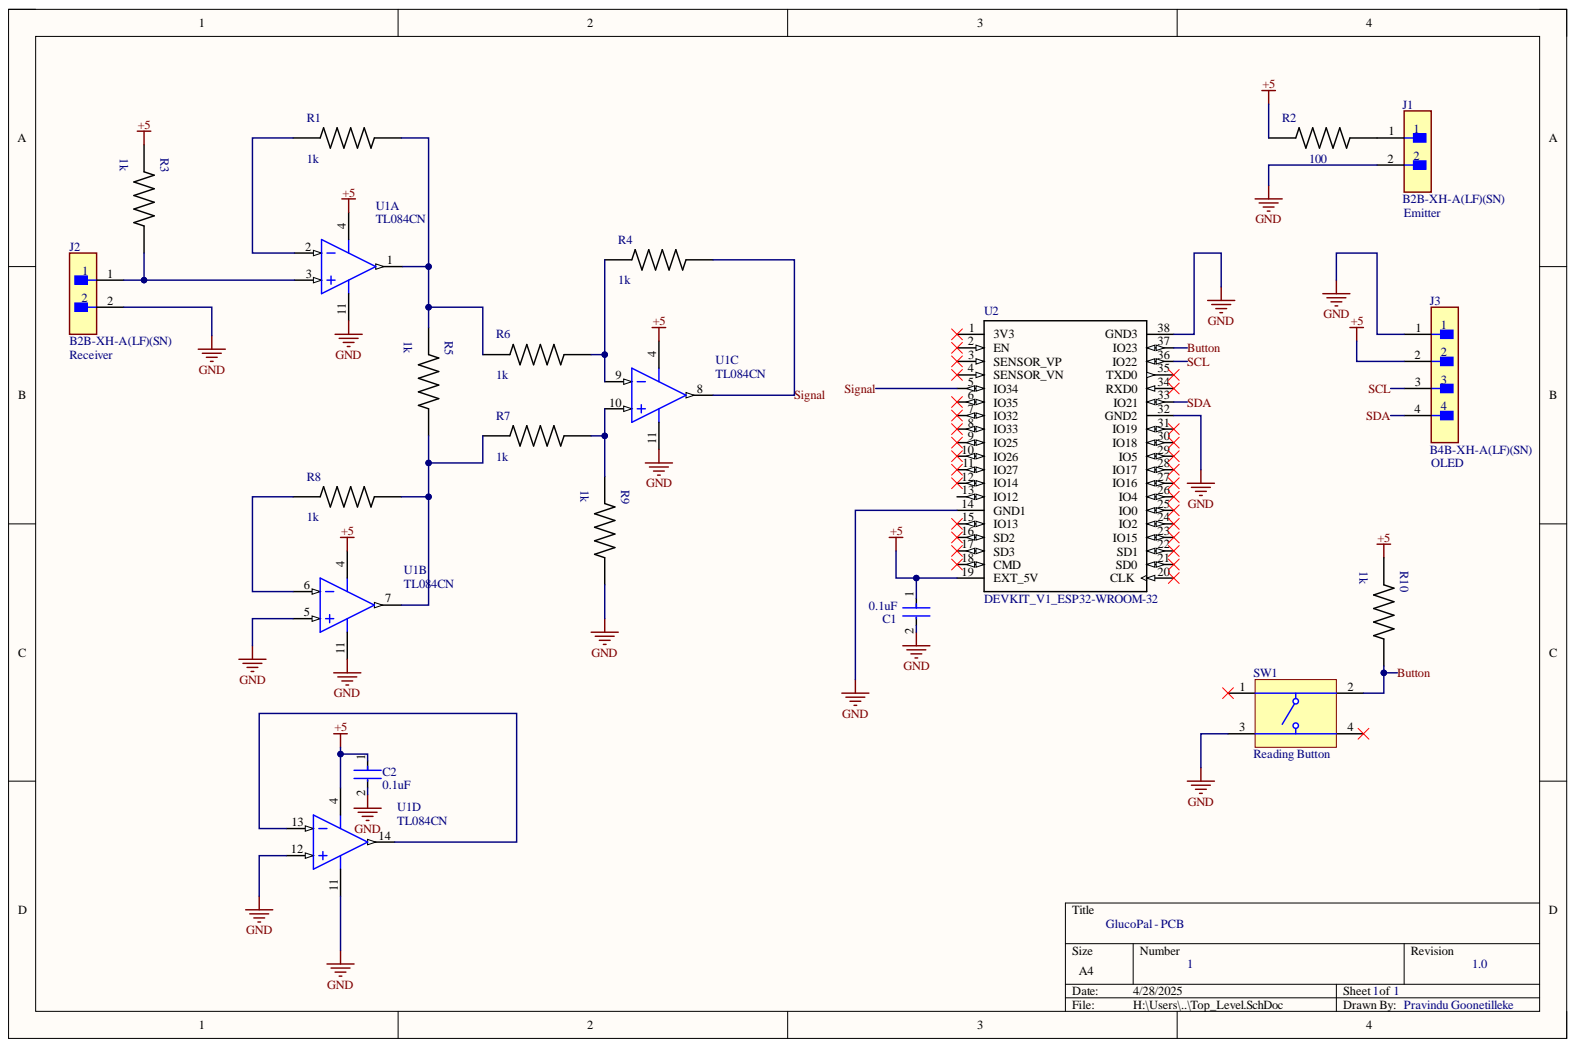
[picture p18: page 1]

Siz e A4 | Numb e r 1 | R evisio n 1. 0

Da te : 4/28/202 5 | She et of 1 1
File : H:\Use rs\. .\Top_Le v e l . S c hD o c | Dr awn B y : P r avindu Goonetil le ke

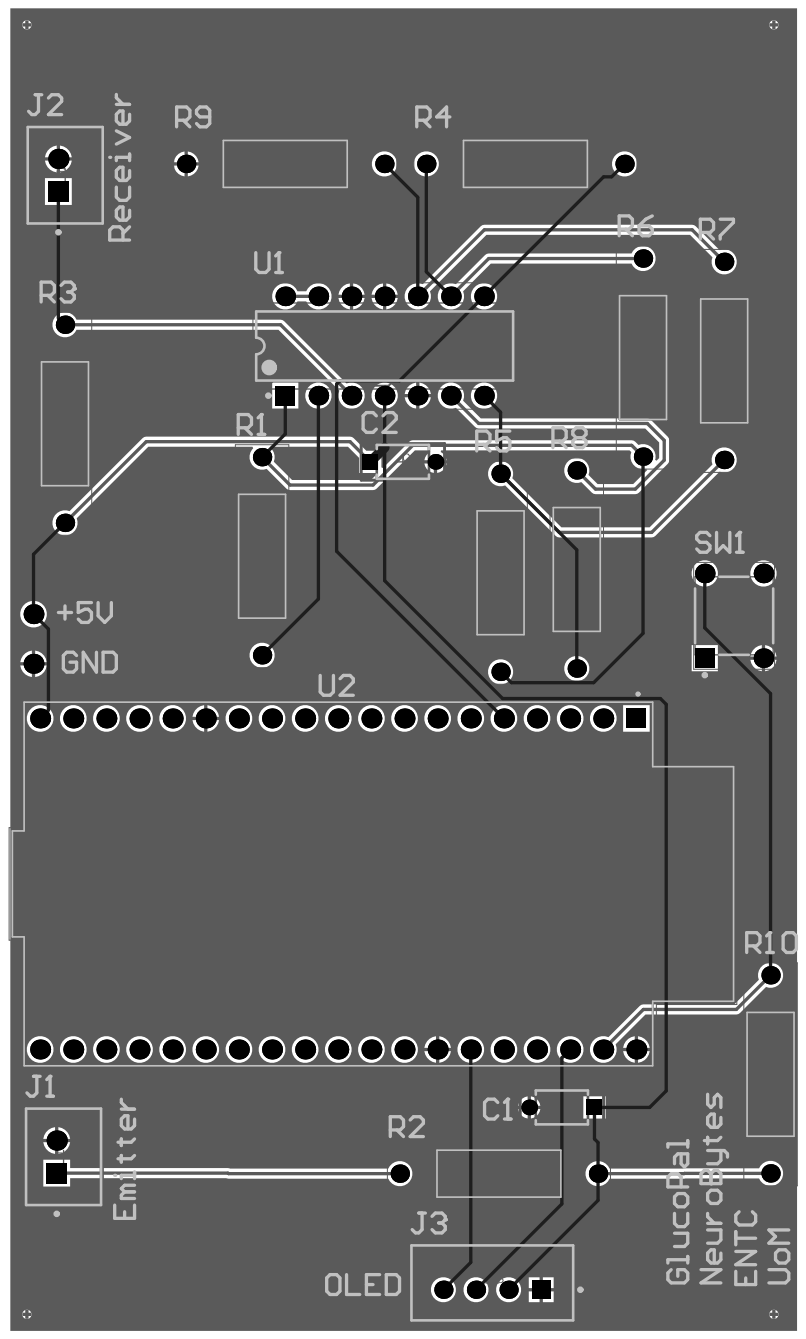
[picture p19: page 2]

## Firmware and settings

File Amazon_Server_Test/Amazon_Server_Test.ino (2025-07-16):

#include <WiFi.h>
#include <WiFiClientSecure.h>
#include <HTTPClient.h>
#include <Wire.h>
#include <Adafruit_GFX.h>
#include <Adafruit_SSD1306.h>
#include <WebServer.h>

// WiFi credentials
const char* ssid = "";
const char* password = "";
const char* serverURL = ""; // API URL

// Analog read
const int analogPin = 34; // Using GPIO34 (ADC1_CH6)
const int numSamples = 1000; // Collect 1000 samples
int readings[numSamples];

// Button
const int buttonPin = 23; // GPIO23 for exit button

// OLED Display config
#define SCREEN_WIDTH 128
#define SCREEN_HEIGHT 64
#define OLED_RESET    -1  // Reset pin not used
Adafruit_SSD1306 display(SCREEN_WIDTH, SCREEN_HEIGHT, &Wire, OLED_RESET);

// Local HTTP server
WebServer server(8000);  // For receiving glucose data
float receivedGlucose = -1;  // Store last received glucose value

void setup() {
  Serial.begin(115200);
  pinMode(buttonPin, INPUT_PULLUP);

  // Start OLED
  if (!display.begin(SSD1306_SWITCHCAPVCC, 0x3C)) {
    Serial.println(F("SSD1306 allocation failed"));
    while (true);
  }

  display.clearDisplay();
  display.setTextSize(1);
  display.setTextColor(SSD1306_WHITE);
  display.setCursor(0, 0);
  display.println("Starting...");
  display.display();
  delay(1000);
  display.clearDisplay();

  // Connect to WiFi
  WiFi.begin(ssid, password);
  Serial.print("Connecting to WiFi");
  while (WiFi.status() != WL_CONNECTED) {
    delay(500);
    Serial.print(".");
  }
  Serial.println("\nWiFi connected!");
  Serial.print("IP address: ");
  Serial.println(WiFi.localIP());

  // Setup HTTP endpoint to receive glucose result
  server.on("/receive", HTTP_POST, []() {
    if (server.hasArg("plain")) {
      String body = server.arg("plain");
      int glucoseIndex = body.indexOf("glucose");
      if (glucoseIndex != -1) {
        int colon = body.indexOf(":", glucoseIndex);
        int endBrace = body.indexOf("}", colon);
        if (colon != -1 && endBrace != -1) {
          String glucoseStr = body.substring(colon + 1, endBrace);
          receivedGlucose = glucoseStr.toFloat();
          Serial.print("Received glucose: ");
          Serial.println(receivedGlucose);

          // Display glucose on OLED
          display.clearDisplay();
          display.setCursor(0, 0);
          display.setTextSize(1);
          display.println("GLUCOSE:");
          display.setTextSize(2);
          display.setCursor(0, 16);
          display.print(receivedGlucose);
          display.println(" mg/dL");
          display.display();
        }
      }
    }
    server.send(200, "application/json", "{\"message\":\"Glucose received\"}");
  });

  server.begin();
  Serial.println("Local HTTP server started at port 8000");
}

void loop() {
  // Handle any incoming glucose result
  server.handleClient();

  // Collect 1000 analog readings
  Serial.println("Collecting data...");
  display.clearDisplay();

  for (int i = 0; i < numSamples; i++) {
    int sensorValue = analogRead(analogPin);
    readings[i] = 4096 - sensorValue;

    Serial.println(sensorValue);

    int amplifiedValue = sensorValue * 10;
    int y = map(sensorValue, 1900, 2250, SCREEN_HEIGHT, 0);
    y = constrain(y, 0, SCREEN_HEIGHT);
    int x = map(i, 0, numSamples, 0, SCREEN_WIDTH);

    if (x < SCREEN_WIDTH) {
      display.drawPixel(x, y, SSD1306_WHITE);
    }

    if (i % 8 == 0) {
      display.display();
    }

    delay(10); // ~100Hz sampling
  }

  display.display();

  Serial.println("Data collection complete. Sending to server...");

  // Send data to Server
  if (WiFi.status() == WL_CONNECTED) {
    WiFiClientSecure client;
    client.setInsecure();

    HTTPClient https;

    if (https.begin(client, serverURL)) {  // HTTPS
      https.addHeader("Content-Type", "application/json");

      String csvData = "";
      for (int i = 0; i < numSamples; i++) {
        csvData += String(readings[i]);
        if (i < numSamples - 1) csvData += ",";
      }

      String jsonPayload = "{\"values\":[" + csvData + "]}";

      int httpResponseCode = https.POST(jsonPayload);

      if (httpResponseCode > 0) {
        String response = https.getString();
        Serial.print("Server response: ");
        Serial.println(response);

        // *** NEW CODE TO DISPLAY GLUCOSE ON OLED ***
        int glucoseIndex = response.indexOf("glucose");
        if (glucoseIndex != -1) {
          int colon = response.indexOf(":", glucoseIndex);
          int endBrace = response.indexOf("}", colon);
          if (colon != -1 && endBrace != -1) {
            String glucoseStr = response.substring(colon + 1, endBrace);
            receivedGlucose = glucoseStr.toFloat();

            display.clearDisplay();
            display.setCursor(0, 0);
            display.setTextSize(1);
            display.println("GLUCOSE:");
            display.setTextSize(2);
            display.setCursor(0, 16);
            display.print(receivedGlucose);
            display.println(" mg/dL");
            display.display();
          }
        }
      } else {
        Serial.print("Error sending POST. HTTP response code: ");
        Serial.println(httpResponseCode);
      }

      https.end();
    } else {
      Serial.println("Unable to connect");
    }
  } else {
    Serial.println("WiFi disconnected. Cannot send data.");
  }

  // Wait until button is pressed
  Serial.println("Waiting for button press to restart...");
  while (true) {
    server.handleClient(); // Keep checking for glucose result
    if (digitalRead(buttonPin) == LOW) {
      Serial.println("Button pressed! Restarting data collection...");
      delay(500); // debounce
      break;
    }
  }
}
